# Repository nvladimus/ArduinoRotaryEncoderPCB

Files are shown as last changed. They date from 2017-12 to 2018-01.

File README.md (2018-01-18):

# Printed circuit board for rotary encoder control
The purpose of this PCB is to simplify connection of a rotary encoder to Arduino. The PCB contains a circuit for denoising (debouncing) of a rotary encoder ([Sparkfun 10982](https://www.sparkfun.com/products/10982) or [Bourns PEL12T](http://www.bourns.com/data/global/pdfs/PEL12T.pdf),  with RGB illuminated shaft), and also contains load resistors for it's three LEDs. All you need is connect the PCB leads to Arduino digital pins.
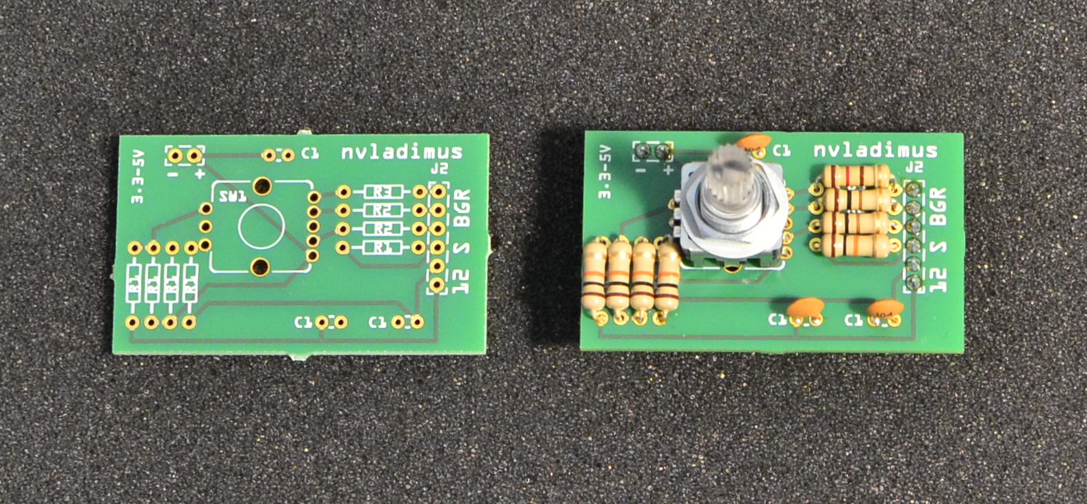
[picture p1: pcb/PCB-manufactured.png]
pcb photo PCB bare (left) and assembled (right)


**Pins:**
* "+" power supply (3.3-5V)
* "-" ground
* 1 and 2 - readout of the quadrature signals 
* S - pushbutton readout
* R,G,B - control pins for red, green and blue LEDs built in the encoder shaft.

**Functions:**
* Denoising the encoder quadrature signals (resistors R1-R4 and capacitors C1,C2)
* Denoising the pushbutton action of the encoder shaft (capacitor C3)
* a pull-up resistor for the pushbutton (resistor R4).
* resistors for R,G,B LEDs of the encoder shaft (resistors R5, R6, R7).

**Usage**

Connect power (+) and ground (-) pins to Arduino 5V and ground, quadrature pins 1,2 to Arduino digital pins with interrupt:
* Arduino Uno: digital pins 2,3
* Arduino Mega: any pair of digital pins	2, 3, 18, 19, 20, 21

Code examples include rotary encoder readout, shaft push-button action, and turning LEDs on/off by the push-button action. Counts are printed out via Serial Monitor, 4 counts per click. Code requires [Encoder](https://github.com/PaulStoffregen/Encoder) library: download and unzip it into your `../Ardunio/libraries/` folder and restart Arduino IDE to install. 

**Number of PCB layers:** 2

**Dimensions:** 30x50 mm (normal version), 30x35mm (SMD version)

**File format**: everything is in Fritzing file format to keep it friendly for non-professionals :-)

**Ordering from AISLER**: 

[30x50 mm (normal version)](https://aisler.net/nvladimus/myboard/debouncing-board-for-rotary-encoder-illuminated-rgb-sparkfun-10982-size-30x50-mm)

[30x35mm (SMD version)](https://aisler.net/nvladimus/myboard/debouncing-board-for-rotary-encoder-illuminated-rgb-sparkfun-10982-smd-style-size-30x35-mm)

More info in my [BLOG](https://high-na.blogspot.com/2017/12/rotaryEncoder.html).

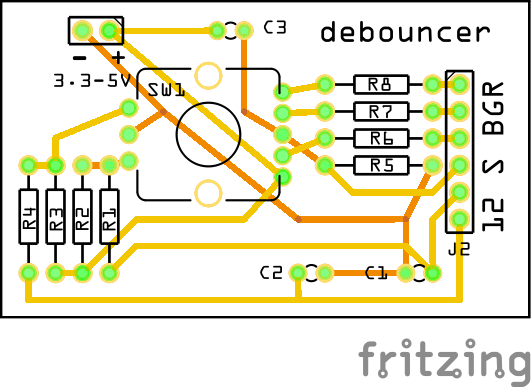
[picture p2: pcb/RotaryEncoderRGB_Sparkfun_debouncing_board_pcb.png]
pcb normal size Normal-size verion, 30x50 mm
 
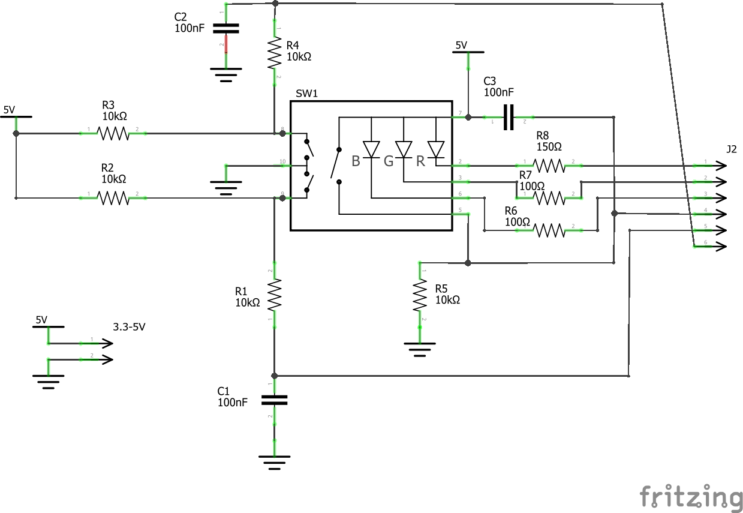
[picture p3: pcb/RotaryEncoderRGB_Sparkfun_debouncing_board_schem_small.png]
Schematics


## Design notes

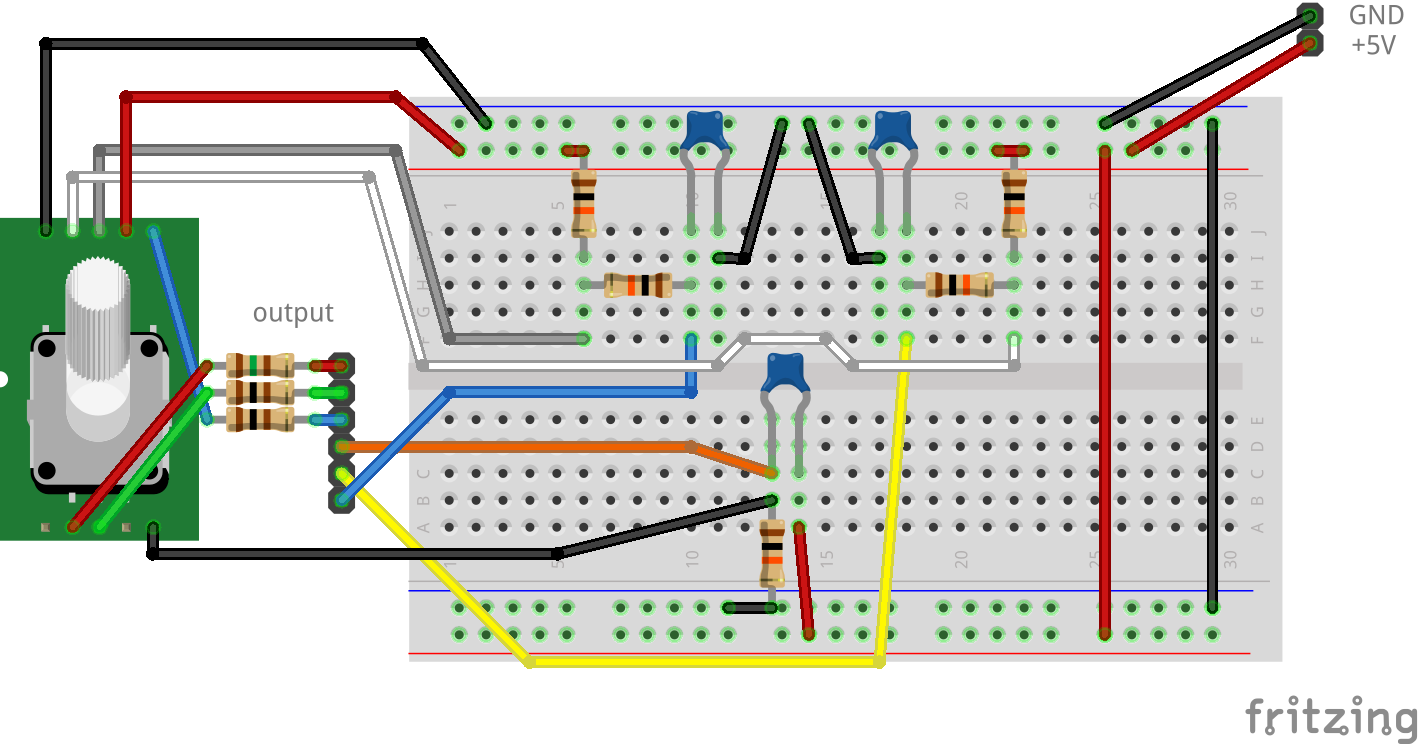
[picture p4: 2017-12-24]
pcb/RotaryEncoderRGB_Sparkfun_debouncing_board_bb.png

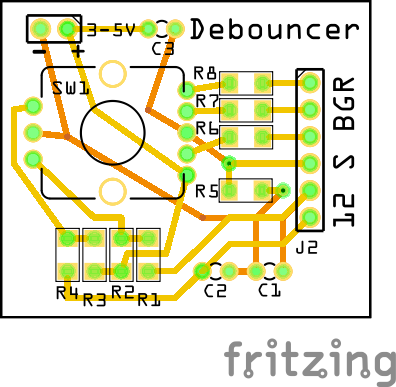
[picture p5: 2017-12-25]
pcb/RotaryEncoderRGB_Sparkfun_debouncing_board_SMD_footprint_pcb.png

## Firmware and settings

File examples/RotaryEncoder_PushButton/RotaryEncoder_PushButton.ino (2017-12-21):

#include <Encoder.h> //encoder library https://www.pjrc.com/teensy/td_libs_Encoder.html

// Change these two numbers to the pins connected to your encoder.
//   Best Performance: both pins have interrupt capability
//   Good Performance: only the first pin has interrupt capability
//   Low Performance:  neither pin has interrupt capability
Encoder myEnc(2,3);
//   avoid using pins with LEDs attached

// set up the button action of the rotary encoder shaft
int buttonState = LOW;
int pinButton = 4;

void setup() {
  Serial.begin(115200);
  Serial.println("Basic Encoder Test:");
  pinMode(pinButton, INPUT);
}

long oldPosition  = -999;

void loop() {
  long newPosition = myEnc.read();
  if (newPosition != oldPosition) {
    oldPosition = newPosition;
    Serial.println(newPosition);
  }
  //read the button state
  int reading = digitalRead(pinButton);
  if(reading != buttonState){
    buttonState = reading;
    if(buttonState == HIGH){
        Serial.println("button pressed");
    }
  }
}

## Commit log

2017-12-20 + rotary encoder example
2017-12-21 + 3 examples of Arduino code
2017-12-24 added pcb files
    [Rotary Encoder RGB Sparkfun debouncing board.fzz, Rotary Encoder RGB Sparkfun debouncing board_SMD_footprint.fzz]
2017-12-24 added PCB photo
2017-12-24 changed file names
    [RotaryEncoderRGB_Sparkfun_debouncing_board.fzz, RotaryEncoderRGB_Sparkfun_debouncing_board_SMD_footprint.fzz]
2017-12-24 fixed resistor labels
2017-12-25 fixed thin wires in SMD
    [RotaryEncoderRGB_Sparkfun_debouncing_board_SMD_footprint.fzz]
2017-12-25 fixed thin wires in SMD png
2017-12-25 changed schematic image size
2017-12-25 fixed ratnest wire
    [RotaryEncoderRGB_Sparkfun_debouncing_board_SMD_footprint.fzz]
